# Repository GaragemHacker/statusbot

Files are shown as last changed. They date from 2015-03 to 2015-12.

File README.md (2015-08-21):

# statusbot
Clever Joke Bot to make the Garage more acessible in the web

### Task's (to-do's)

 * Python Chatter Bot on IRC
 * HackerSpace Door status
 * ~~Yowsup intergation~~
 * Telegram @ElviraBot(raimundod.py)
 * WebSite and Wiki hackerspace status

### status.php

Para passar o status do hackerspace como aberto, foi optado por usar o status.php que grava um arquivo status.txt com o estado do hackerspace. A requisicao e feito por um arduino com ethernet shield.

-------

### statusbot(turnkey/push).ino

Statusbot task's com Arduino
 - [x] Receber DHCP
 - [x] Imprimir tudo que estiver colhendo em Serial
 - [x] Aceitar requisicoes ping
 - [x] Fazer UrlRequest <i>(quando o estado se alterar)</i>
 - [ ] Twittar Status

Estou deixando para estudo de caso duas versões diferentes para arduino.
A versao <i>"turnkey"</i> usa a interrupcao como leitura e pode ser usado com botoes tradicionais tipo switch. O arquivo statusbot_push.ino tem um algoritimo que ira funcionar com botoes <i>"push"</i>. 

#### Exemplos de botoes
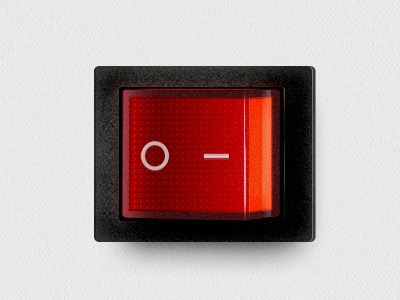
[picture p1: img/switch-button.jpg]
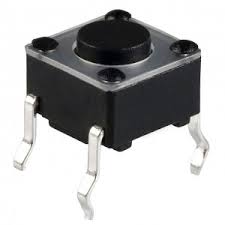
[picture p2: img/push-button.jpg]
  | 
------------- | -------------
<i>Switch Gangorra</i>  | <i>Push button</i>

-------

### ircbot.py

Chatter bot, para notificao de status com WhatsApp e IRC
 * Notificao de presenca no HackerSpace pelo IRC
 * Aviso da abertura para WhatsApp com integracao ao yowsup
 * Auto voices novos visitantes do canal
 * Vocabulario atrevido de respostas

-------

### lamp.js/lamp.php (<i>lamp_sample.html</i>)
Pequeno exemplo de como usar a API para colher o estado da garagem.
O exemplo que usa um javascript colhe o estado do arquivo status.txt e quando aberto mostra uma lampada acesa no html. Quando apagado mostra uma lampada apagada.
O que esta php faz exatamente a mesma coisa em php :stuck_out_tongue:

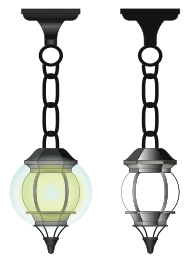
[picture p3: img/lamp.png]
<br>
<i>Lampada usada no site da <a href="http://www.garagemhacker.org">garagemhacker</a></i>

-------

### raiumundod.py

O raimundo tambem conhecido como @RaimundaBot, e o bot atual do telegram da Garagem. 
Este bot deve fazer as seguintes funcoes:

 - [x] Verificar o status da garagem se esta aberta o fechada "/status"
 - [ ] Ecoar as conversar do telegram no canal do irc
 - [ ] Mostrar quem esta na garagem pelo comando "/quemtala" 
 - [ ] Dizer algumas frases legais quando for mencionado 

-------

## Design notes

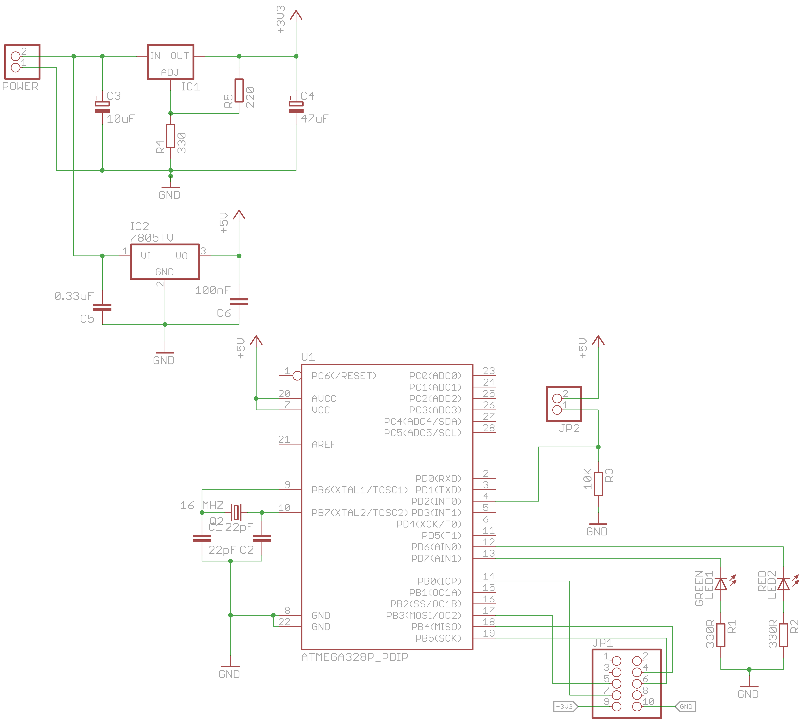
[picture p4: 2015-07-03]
eagle/StatusBot/StatusBot-1-sch.png

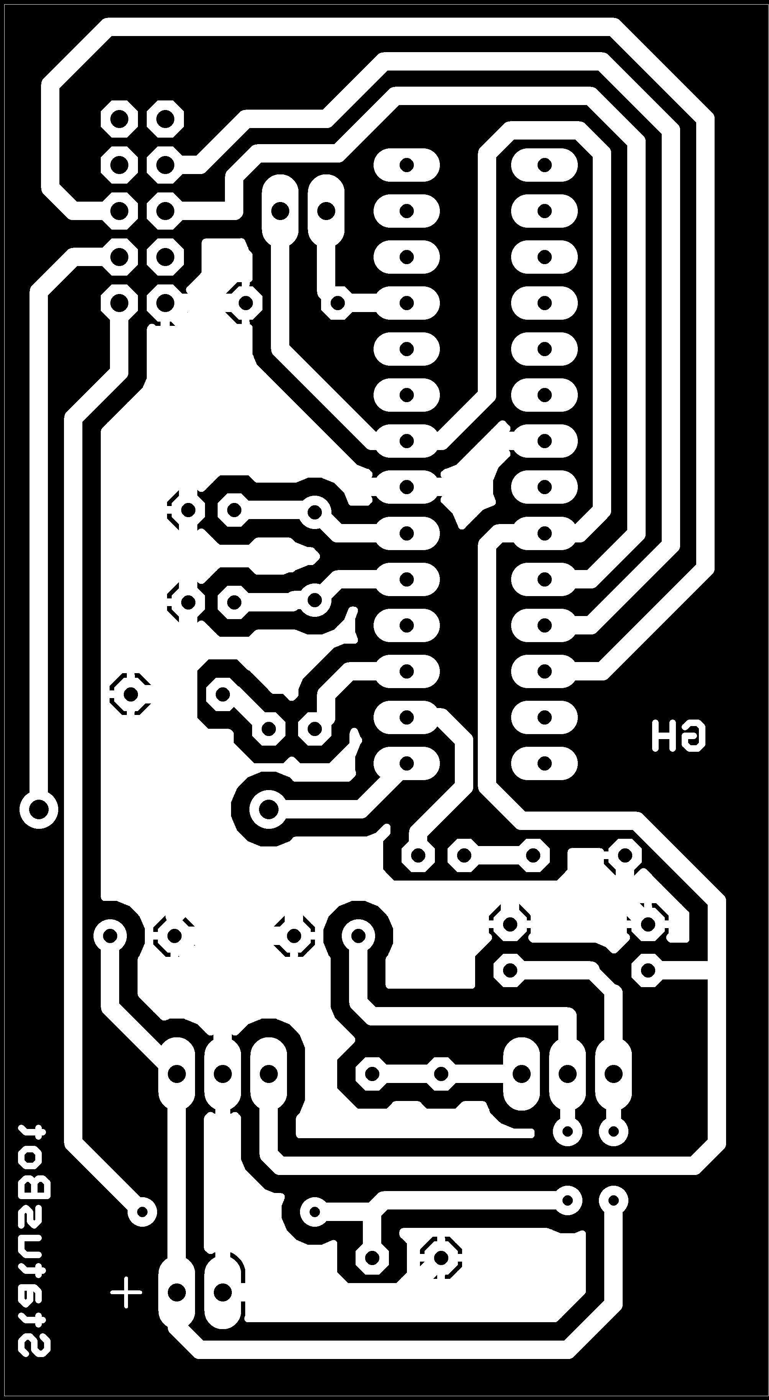
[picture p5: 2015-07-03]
eagle/StatusBot/StatusBot-1.sol.png

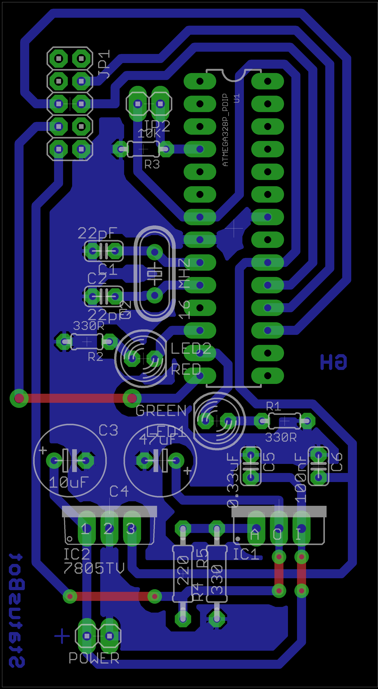
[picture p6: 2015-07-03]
eagle/StatusBot/StatusBot-1.png

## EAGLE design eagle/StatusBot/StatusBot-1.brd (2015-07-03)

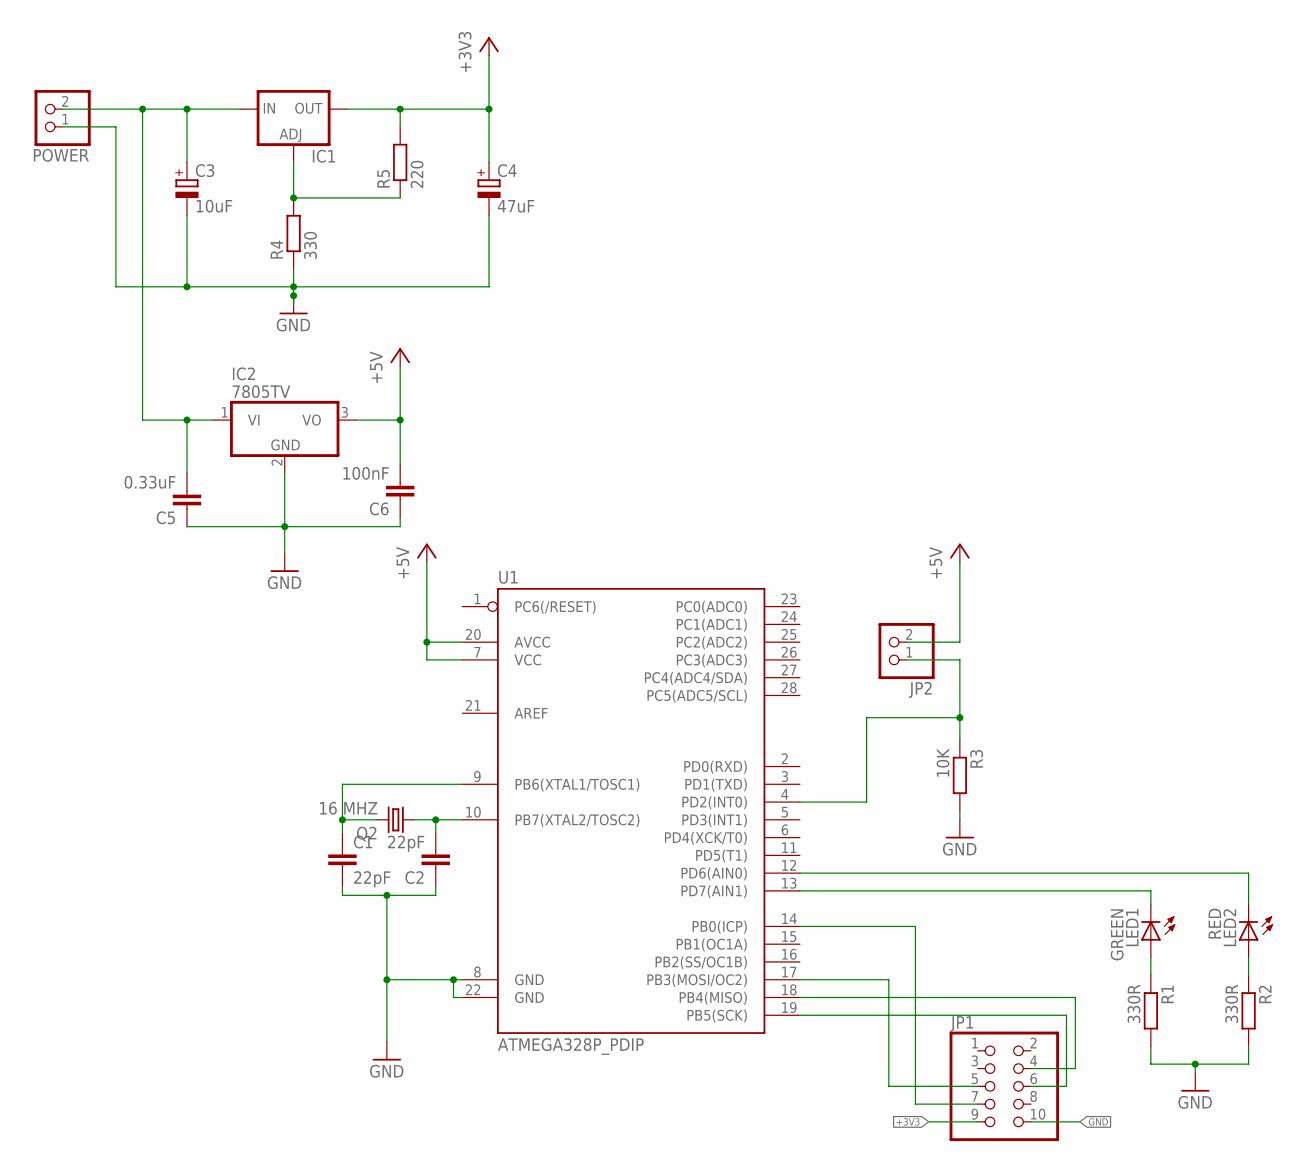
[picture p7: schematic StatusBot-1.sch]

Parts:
C1, C2: 22pF; C025-024X044
C3: 10uF; E3,5-8
C4: 47uF; E3,5-8
C5: 0.33uF; C025-024X044
C6: 100nF; C025-024X044
IC1: LM317TS; 317TS
IC2: 7805TV; TO220V
JP1: PINHD-2X5; 2X05
JP2: PINHD-1X2; 1X02
LED1: GREEN; LED5MM
LED2: RED; LED5MM
POWER: PINHD-1X2; 1X02
Q2: 16 MHZ; HC49/S
R1, R2: 330R; 0204/5
R3: 10K; 0204/5
R4: 330; 0207/10
R5: 220; 0207/10
U1: ATMEGA328P_PDIP; DIL28-3

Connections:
+3V3: C4.+, IC1.2 (OUT), JP1.9, R5.2
+5V: C6.2, IC2.3 (VO), JP2.2, U1.7 (VCC), U1.20 (AVCC)
GND: C1.2, C2.1, C3.-, C4.-, C5.1, C6.1, IC2.2 (GND), JP1.10, POWER.1, R1.2, R2.2, R3.2, R4.1, U1.8 (GND), U1.22 (GND)
unnamed: C2.2, Q2.1, U1.10 (PB7(XTAL2/TOSC2))
unnamed: JP1.7, U1.14 (PB0(ICP))
unnamed: JP2.1, R3.1, U1.4 (PD2(INT0))
unnamed: C1.1, Q2.2, U1.9 (PB6(XTAL1/TOSC1))
unnamed: C3.+, C5.2, IC1.3 (IN), IC2.1 (VI), POWER.2
unnamed: LED1.A, R1.1
unnamed: LED2.A, R2.1
unnamed: JP1.5, U1.17 (PB3(MOSI/OC2))
unnamed: LED2.K (C), U1.12 (PD6(AIN0))
unnamed: LED1.K (C), U1.13 (PD7(AIN1))
unnamed: JP1.4, U1.18 (PB4(MISO))
unnamed: JP1.6, U1.19 (PB5(SCK))
unnamed: IC1.1 (ADJ), R4.2, R5.1

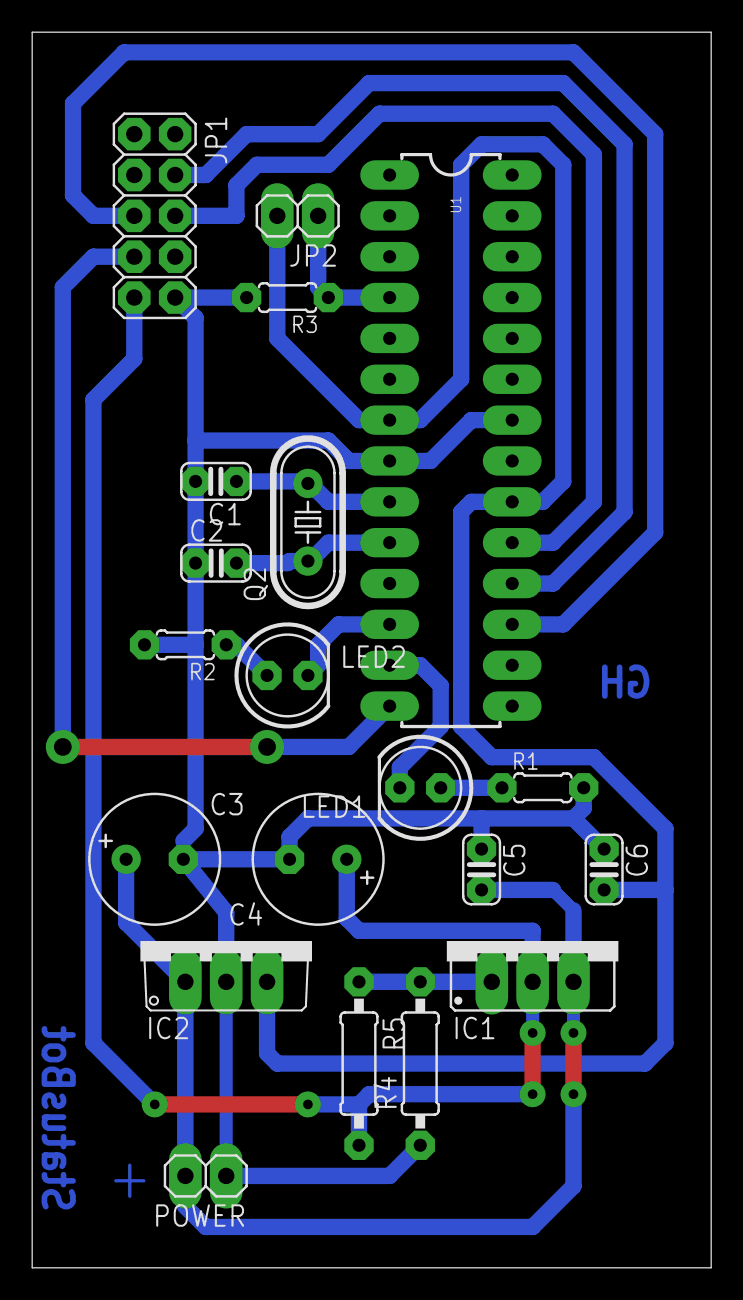
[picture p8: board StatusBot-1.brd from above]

Board: 2 copper layers, 42.2 x 76.8 mm, 20 parts (0 on the bottom side), 16 nets.

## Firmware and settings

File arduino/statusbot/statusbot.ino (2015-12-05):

//GaragemHacker - StatusBot
/*
--> babysteps desse projeto
Objetivo: Requisitar uma pagina web usando metodo get para
indicar se o hackerspace esta aberto ou fechado.

- Arduino Ethercard ENC28J60 https://github.com/jcw/ethercard
- Este bot deve usar DHCP com MAC Amarrado ao nosso servidor local
- Caso conectemos via serial ele deve ecoar todos os parametros que ele possui
- Pode receber pings para mostar que esta vivo
- Se o status do botao estiver ligado deve requisitar a pagina para abrir e acender o led verde
- Se o status do botao for desligado deve requisitar a pagina para fechar e acender o led vermelho

*/

//Incluindo a lib Ethercard --> https://github.com/jcw/ethercard/archive/master.zip
#include <EtherCard.h>

int ledgreen = 7; //iniciar led verde na porta 7
int ledred = 6; //iniciar led vermelho na porta 6
int botao = 2; //iniciar botao na porta 6
int buttonState;//the current reading from the input pin
int lastButtonState = LOW;//set lastbutton state to LOW


//Iniciando o ethernet shield com o mac abaixo
static byte mymac[] = { 0x74,0x69,0x69,0x2D,0x30,0x31 };
byte Ethernet::buffer[700];
static uint32_t timer;

//quem vou disparar o acesso
const char website[] PROGMEM = "garagemhacker.org";

//funcao para dnsLookup (traducao de ip)
static void look(){
  //condicional para fazer o dnslookup para trazer o callback da requisicao
  if (!ether.dnsLookup(website))
    Serial.println(F("DNS failed"));    
    ether.printIp(F("SRV: "), ether.hisip);
}

//funcao de callback - retorna a pagina que foi requisitada
static void get_callback(byte status, word off, word len) {
  Serial.println(F(">>>"));
  Ethernet::buffer[off+300] = 0;
  Serial.print((const char*) Ethernet::buffer + off);
  Serial.println(F("..."));
}


//funcao pra ecoar de quem esta me pingando
static void pingado (byte* ptr) {
  ether.printIp(">>>fui pingado por: ", ptr);
   timer = -9999999; // start timing out right away
  Serial.println();
}

//Esta funcao para iniciarmos o DHCP
static void dhcp() {
  if (ether.begin(sizeof Ethernet::buffer, mymac) == 0) {
    Serial.println(F("Failed to access Ethernet controller"));
  };
  
//Inicio dos ecos em serial de todos os dados que a placa tiver
//pequeno loop pra mostar o MAC ADRESS
  Serial.print("MAC: ");
  for (byte i=0;i<6;i++){
    Serial.print(mymac[i], HEX);
    if (i == 5){Serial.println();break;}
    Serial.print(":");
  }
  ether.printIp("IP:  ", ether.myip); //imprimindo o ip
  ether.printIp("Mask: ", ether.netmask); //mascara de subrede
  ether.printIp("GW:  ", ether.gwip); //gateway
  ether.printIp("DNS:  ", ether.dnsip); //dns
  ether.printIp("BROADCAST:  ", ether.broadcastip); //broadcast
  ether.printIp("DHCP server: ", ether.dhcpip); //servidor de onde veio o DHCP
}

//funcao para alternar os leds pelo estado do botao
static void ledchange(){
// set initial LED state  
  int reading = digitalRead(botao);
  if (reading == LOW){   
      digitalWrite(ledred, HIGH);
      digitalWrite(ledgreen,LOW);
  }
  else{
      digitalWrite(ledred,LOW );
      digitalWrite(ledgreen,HIGH);
  }
}


//My debouncing settings (solve button debouce)
long lastDebounceTime = 0; 
long debounceDelay = 50;

//Inicializacao dos recursos.  
void setup() {
  pinMode (ledgreen, OUTPUT);
  pinMode (ledred, OUTPUT);
  pinMode (botao, INPUT);
  Serial.begin(57600);//usamos serial para ecos dos dados.
  Serial.println(F("Iniciando"));
 
  dhcp(); //chama a funcao pra iniciar o dhcp
  look();
  ether.registerPingCallback(pingado);//chama esse report para receber os pings
  //ether.parseIp(ether.hisip, "10.10.10.10");//Seta um ip em hisip

  //iniciar com o led na mesma posicao do botao
  ledchange();
  
}

void loop () {
   
  //Receber pings e troca de dados
  word len = ether.packetReceive(); //permite receber pacotes
  word pos = ether.packetLoop(len); //responde os pings que entrarem

  int reading = digitalRead(botao);
   if (reading != lastButtonState) {
    // reset the debouncing timer
    lastDebounceTime = millis();
  }
 
  if ((millis() - lastDebounceTime) > debounceDelay) {
    // whatever the reading is at, it's been there for longer
    // than the debounce delay, so take it as the actual current state:

    // if the button state has changed:
    if (reading != buttonState) {
      buttonState = reading;
      ledchange();
      if (buttonState == HIGH){
        Serial.println("abriu!!! ;p");
        ether.browseUrl(PSTR("/status.php?"), "operacao=abrir", website, get_callback);
      }
      else{
        Serial.println("fechou!!! ;(");
        ether.browseUrl(PSTR("/status.php?"), "operacao=fechar", website, get_callback);
      }
    }
  }
 
  // set the LED:
  
  // save the reading.  Next time through the loop,
  // it'll be the lastButtonState:
  lastButtonState = reading;

}

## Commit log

2015-03-04 Descricao de modificacoes
    novas modificacoes descriminadas
2015-03-04 statusbot com arduino
    Teste inicial do StatusBot
2015-03-07 Add IRQ button switch on Arduino StatusBot
2015-03-07 Add arduino integration Minor changes
2015-03-12 Add push and switch version
2015-03-14 Improve names for Arduino IDE
2015-03-18 Split files to make a sample
2015-03-20 better explanation
    Better explanation for how use status.txt API with js and html sample
2015-03-27 sample python urllib
2015-03-28 fix little bugs - stay fully working
    [push.ino, statusbot.ino, turnkey.ino]
2015-03-30 present the web samples
    Leia, entenda e use!!!
2015-04-02 fix crash when socket failed
2015-04-23 Added timeout for socket when expires leasetime. It means, this bot now save last ping server time and compare it with current time if its exceed the leasetime variable value it try's to reconnect.
2015-05-07 minor improvements for socket exception
2015-05-07 trash threading code
2015-07-01 Error when conected fail
    [statusbot.ino]
2015-07-03 PCB Statusbot
    [StatusBot-1.brd, StatusBot-1.sch]
2016-02-10 improve sample for faster 301

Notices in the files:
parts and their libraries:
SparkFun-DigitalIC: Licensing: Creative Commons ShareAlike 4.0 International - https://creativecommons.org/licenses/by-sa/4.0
